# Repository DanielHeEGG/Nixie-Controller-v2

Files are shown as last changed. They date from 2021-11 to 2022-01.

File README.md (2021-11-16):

# Nixie Clock Controller v2
The most overpowered 6-tube nixie clock controller ever created.

For more details on the project, see [Hackaday Page](https://hackaday.io/project/181819-nixie-clock-controller-v2).

Sockets designed to work with this controller are in the [NCv2-Sockets](https://github.com/DanielHeEGG/NCv2-Sockets) repo.

Firmware files are in the [NCv2-Firmware](https://github.com/DanielHeEGG/NCv2-Firmware) repo.

> **WARNING:**
> This project contains EXPOSED and UNMARKED HIGH VOLTAGE contacts, replicate at your own risk.
## License
This project is licensed under the [Creative Commons Attribution-ShareAlike 4.0 International License](http://creativecommons.org/licenses/by-sa/4.0/).

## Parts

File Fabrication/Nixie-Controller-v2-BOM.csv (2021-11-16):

Reference | Quantity | Value | Footprint | Datasheet | Manufacturer | Part#
A1 | 1 | ESP32-WROOM-32E | RF_Module:ESP32-WROOM-32
BT1 | 1 | BACKUP | Battery:BatteryHolder_Keystone_1058_1x2032 | ~ | Keystone | 1058
C1 | 1 | 100uF | Capacitor_Tantalum_SMD:CP_EIA-7343-43_Kemet-X | ~ | Kemet | T510X107M020ATE045
C15 | 1 | 4.7uF | Capacitor_SMD:C_0603_1608Metric | ~ | Yageo | CC0603MRX5R5BB475
C24 | 1 | 47uF | Capacitor_SMD:CP_Elec_5x5.3 | ~ | Nichicon | UWF0J470MCL1GB
C3 | 1 | 10uF | Capacitor_SMD:CP_Elec_10x10 | ~ | Nichicon | UUX2E100MNL1GS
C2 C4 C5 C6 C7 C8 C13 C14 C16 C17 C18 C19 C20 C21 C22 C23 C26 C27 C28 C29 C30 C31 C32 C33 | 24 | 100nF | Capacitor_SMD:C_0402_1005Metric | ~ | Yageo | CC0402KRX7R8BB104
C9 C10 C11 C12 | 4 | 10uF | Capacitor_SMD:CP_Elec_6.3x7.7 | ~ | Nichicon | UUL1H100MCL1GS
D1 | 1 | ~ | Diode_SMD:D_SMB | ~ | Vishay | ES2F
L1 | 1 | 47uH | Inductor_SMD:L_Bourns_SRR1210A | ~ | Bourns | SRR1210A-470M
Q1 | 1 | ~ | Package_TO_SOT_SMD:TO-252-2 | ~ | IXYS | IXFY26N30X3
Q2 Q3 Q4 Q5 Q6 Q7 Q8 Q9 Q10 Q11 Q12 Q13 Q14 Q15 Q16 Q17 Q18 Q19 Q20 Q21 Q22 Q23 Q24 Q25 Q26 Q27 Q28 Q29 Q30 Q31 Q32 Q33 Q34 Q35 Q36 Q37 Q38 Q39 Q40 Q41 Q42 Q43 Q44 Q45 Q46 Q47 Q48 Q49 Q50 Q51 Q52 Q53 Q54 Q55 Q56 Q57 Q58 Q59 Q60 Q61 | 60 | ~ | Package_TO_SOT_SMD:SOT-23 | ~ | Nexperia | MMBTA42
R1 | 1 | 1.2M | Resistor_SMD:R_0805_2012Metric | ~ | Yageo | RC0805FR-071M2L
R14 R29 R40 R51 R62 R73 | 6 | 470 | Resistor_SMD:R_0402_1005Metric | ~ | Yageo | RC0402FR-07470RL
R2 | 1 | 0.05 | Resistor_SMD:R_2010_5025Metric | ~ | Yageo | PE2010FKE070R05L
R3 R4 R5 R6 R7 R8 R9 R10 R11 R12 R13 R15 R16 R17 R18 R19 R20 R21 R22 R23 R24 R25 R26 R27 R30 R31 R32 R33 R34 R35 R36 R37 R38 R39 R41 R42 R43 R44 R45 R46 R47 R48 R49 R50 R52 R53 R54 R55 R56 R57 R58 R59 R60 R61 R63 R64 R65 R66 R67 R68 R69 R70 R71 R72 | 64 | 6.8K | Resistor_SMD:R_0402_1005Metric | ~ | Yageo | RC0402FR-076K8L
RV1 | 1 | 5K | Potentiometer_SMD:Potentiometer_Bourns_3214J_Horizontal | ~ | Bourns | 3214J-1-502E
U1 | 1 | MAX1771 | Package_SO:SOIC-8_3.9x4.9mm_P1.27mm | ~ | Maxim | MAX1771CSA
U11 | 1 | M41T01 | Package_SO:SOIC-8_3.9x4.9mm_P1.27mm | ~ | ST Micro | M41T01M6F
U12 | 1 | STM32F103C8 | Package_QFP:LQFP-48_7x7mm_P0.5mm | ~ | ST Micro | STM32F103C8T6
U9 U13 U15 U17 U19 U21 | 6 | OPA180 | Package_TO_SOT_SMD:SOT-23-5 | ~ | TI | OPA180IDBVT
U10 U14 U16 U18 U20 U22 | 6 | 74HC4067 | Package_SO:SOIC-24W_7.5x15.4mm_P1.27mm | ~ | TI | CD74HC4067M
U2 | 1 | BH2226 | Package_SO:SOIC-16_4.55x10.3mm_P1.27mm | ~ | Rohm Semi | BH2226F-E2
U3 U4 U5 | 3 | 74HC595 | Package_SO:SOIC-16_3.9x9.9mm_P1.27mm | ~ | TI | CD74HC595M
U6 | 1 | SN74LVCC3245A | Package_SO:SO-24_5.3x15mm_P1.27mm | ~ | TI | SN74LVCC3245ANSR
U7 | 1 | NCP1117-5.0 | Package_TO_SOT_SMD:SOT-223-3_TabPin2 | ~ | ON Semi | NCP1117LPST50T3G
U8 | 1 | NCP1117-3.3 | Package_TO_SOT_SMD:SOT-223-3_TabPin2 | ~ | ON Semi | NCP1117LPST33T3G
Y1 | 1 | 32.768KHz | Crystal:Crystal_SMD_2012-2Pin_2.0x1.2mm | ~ | Seiko | SC20S-12.5PF20PPM

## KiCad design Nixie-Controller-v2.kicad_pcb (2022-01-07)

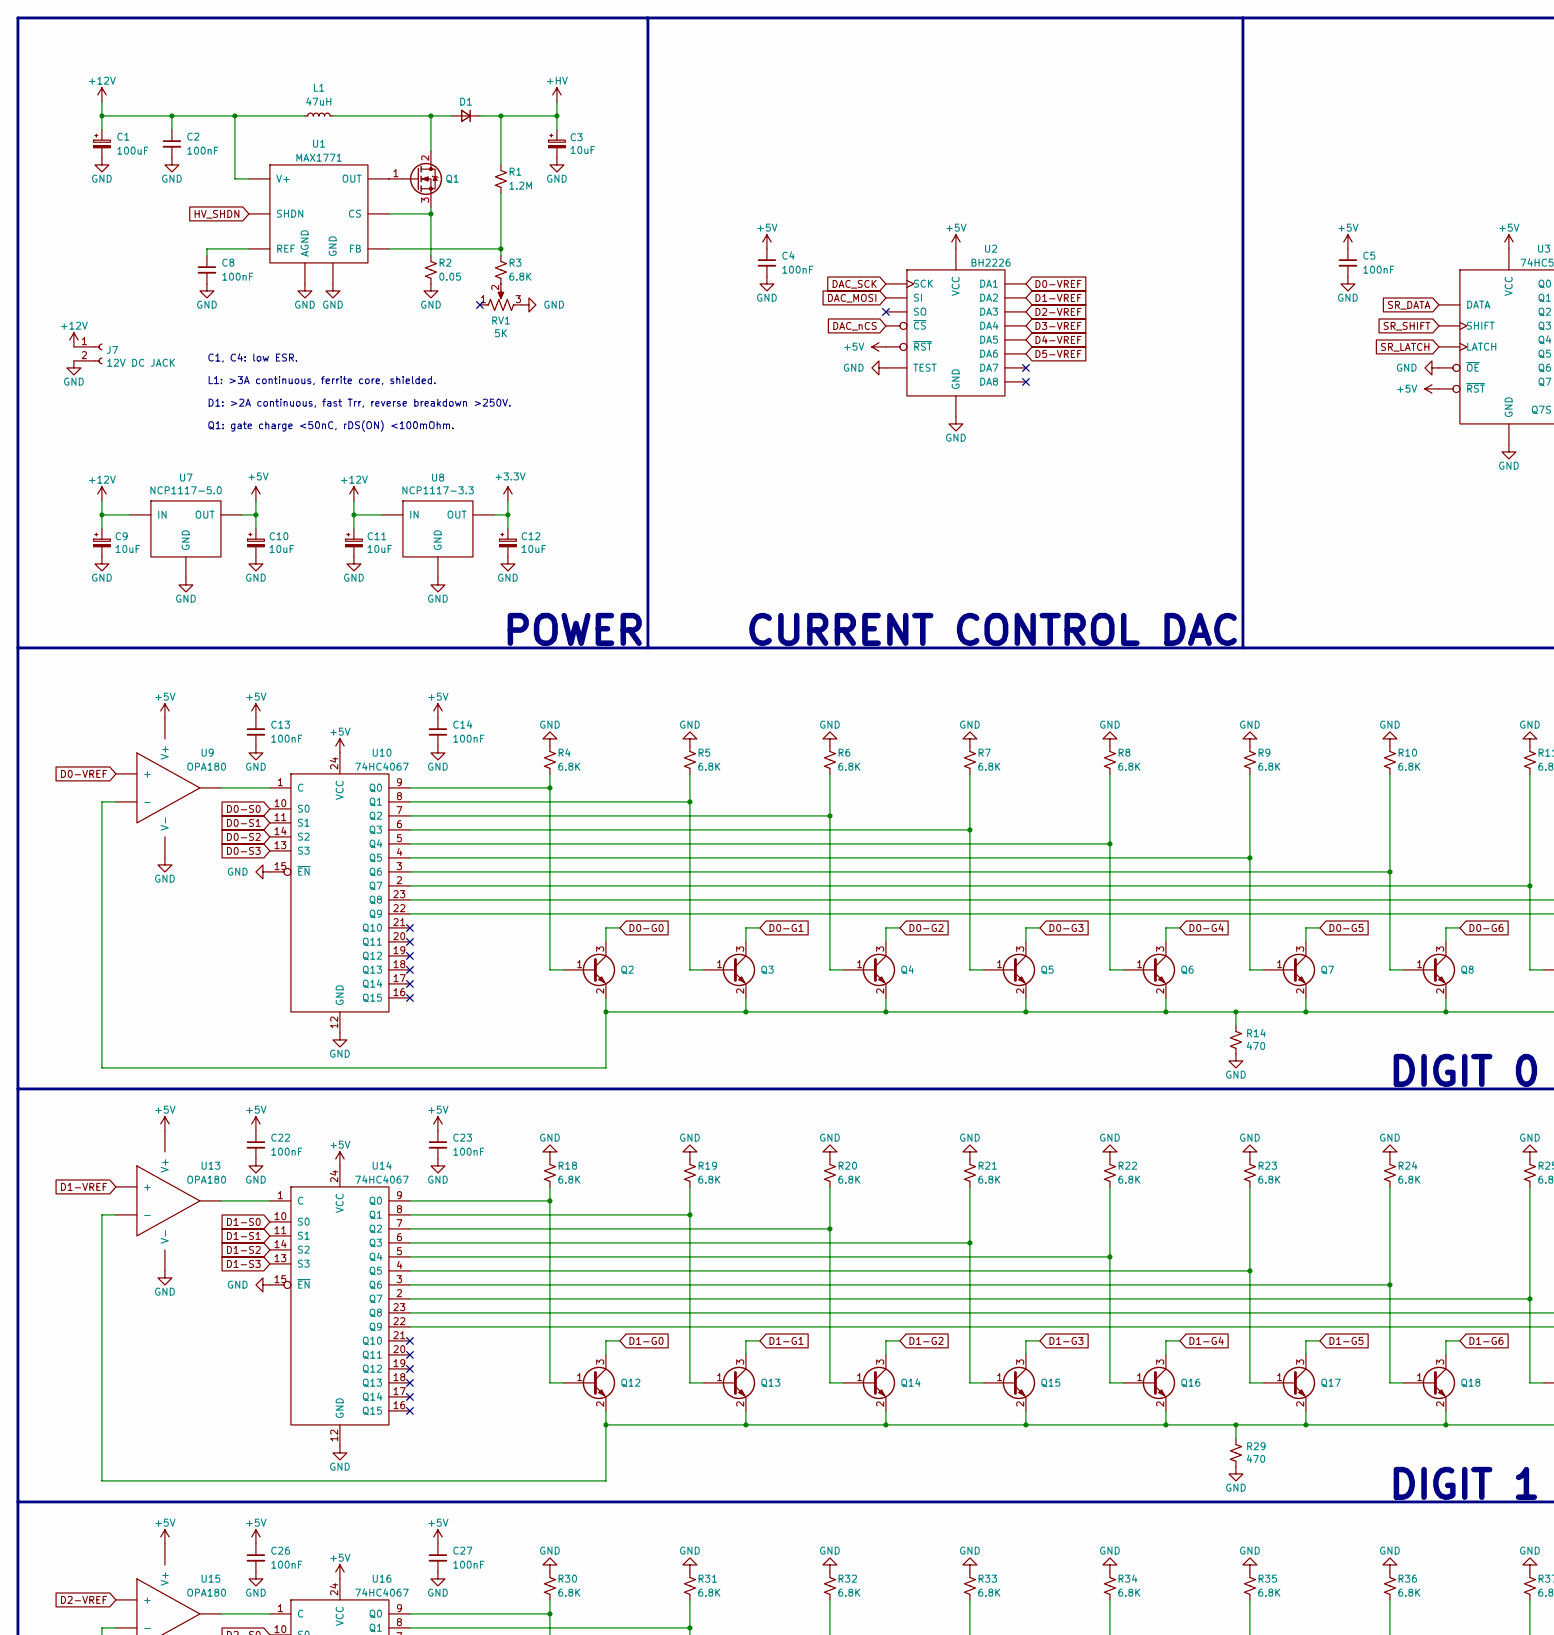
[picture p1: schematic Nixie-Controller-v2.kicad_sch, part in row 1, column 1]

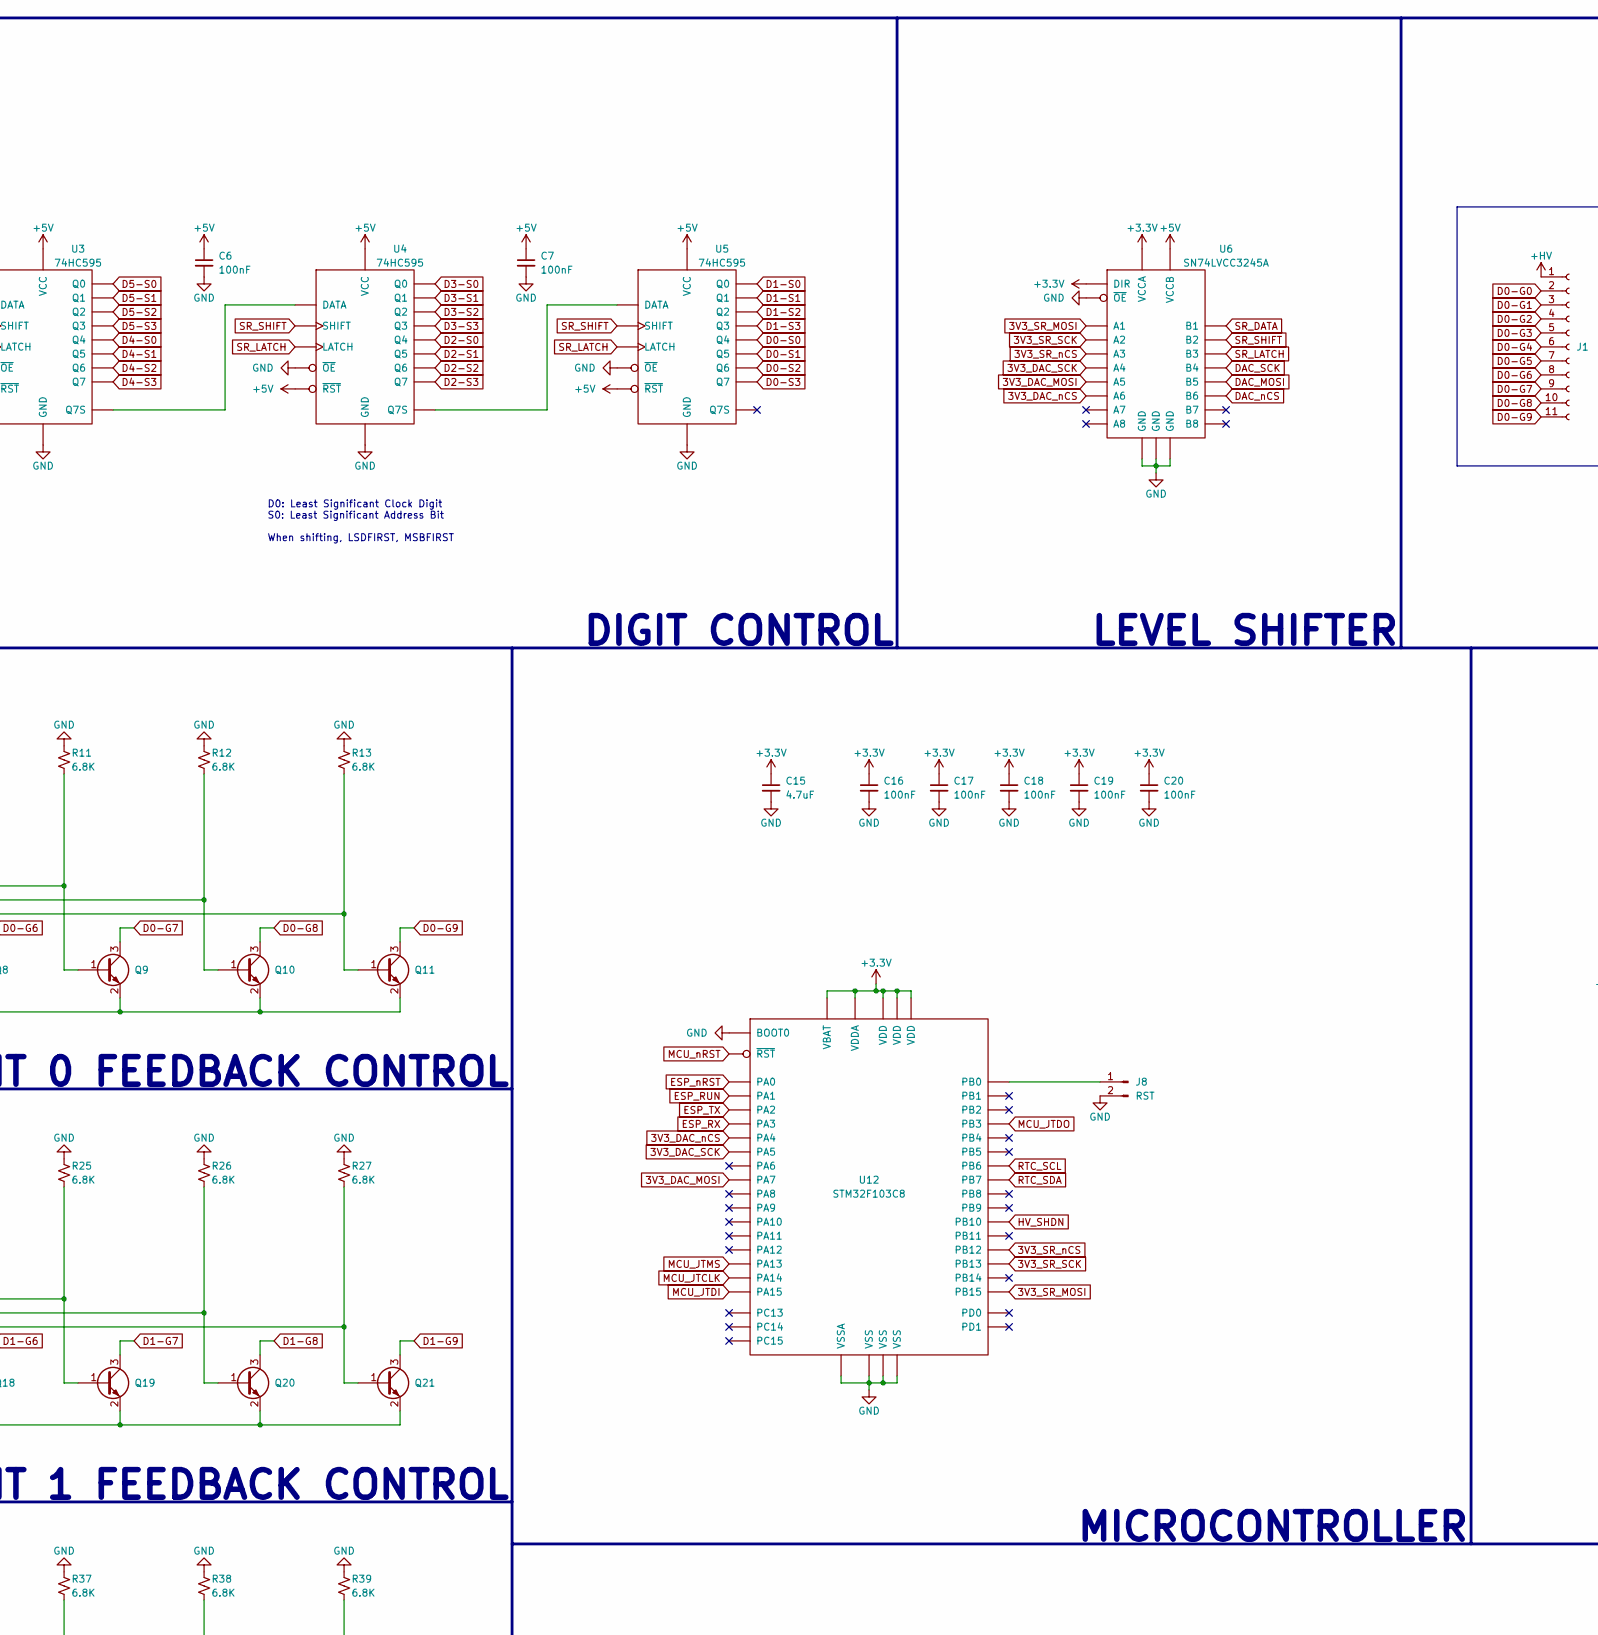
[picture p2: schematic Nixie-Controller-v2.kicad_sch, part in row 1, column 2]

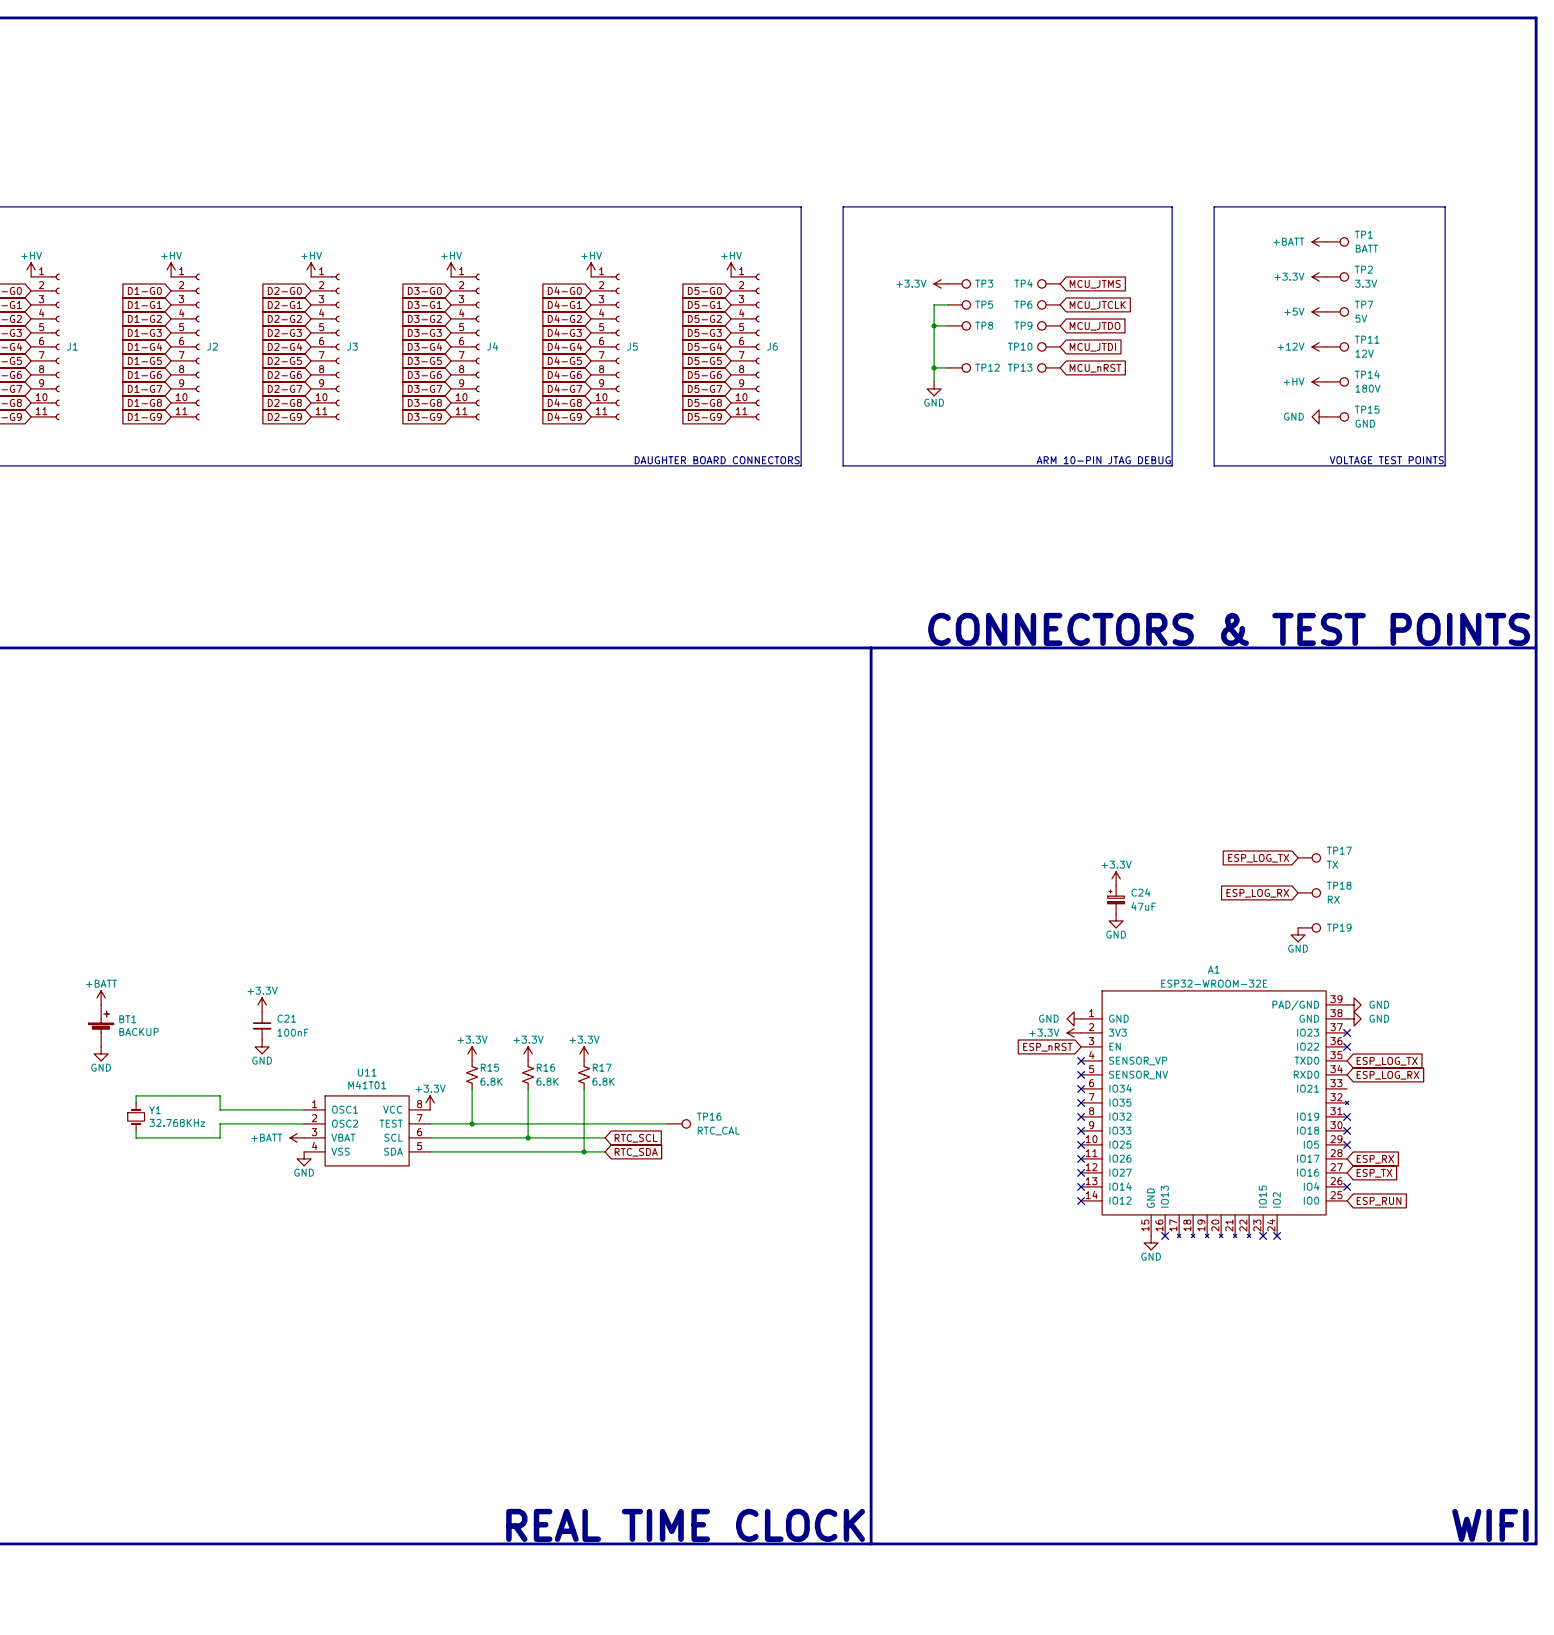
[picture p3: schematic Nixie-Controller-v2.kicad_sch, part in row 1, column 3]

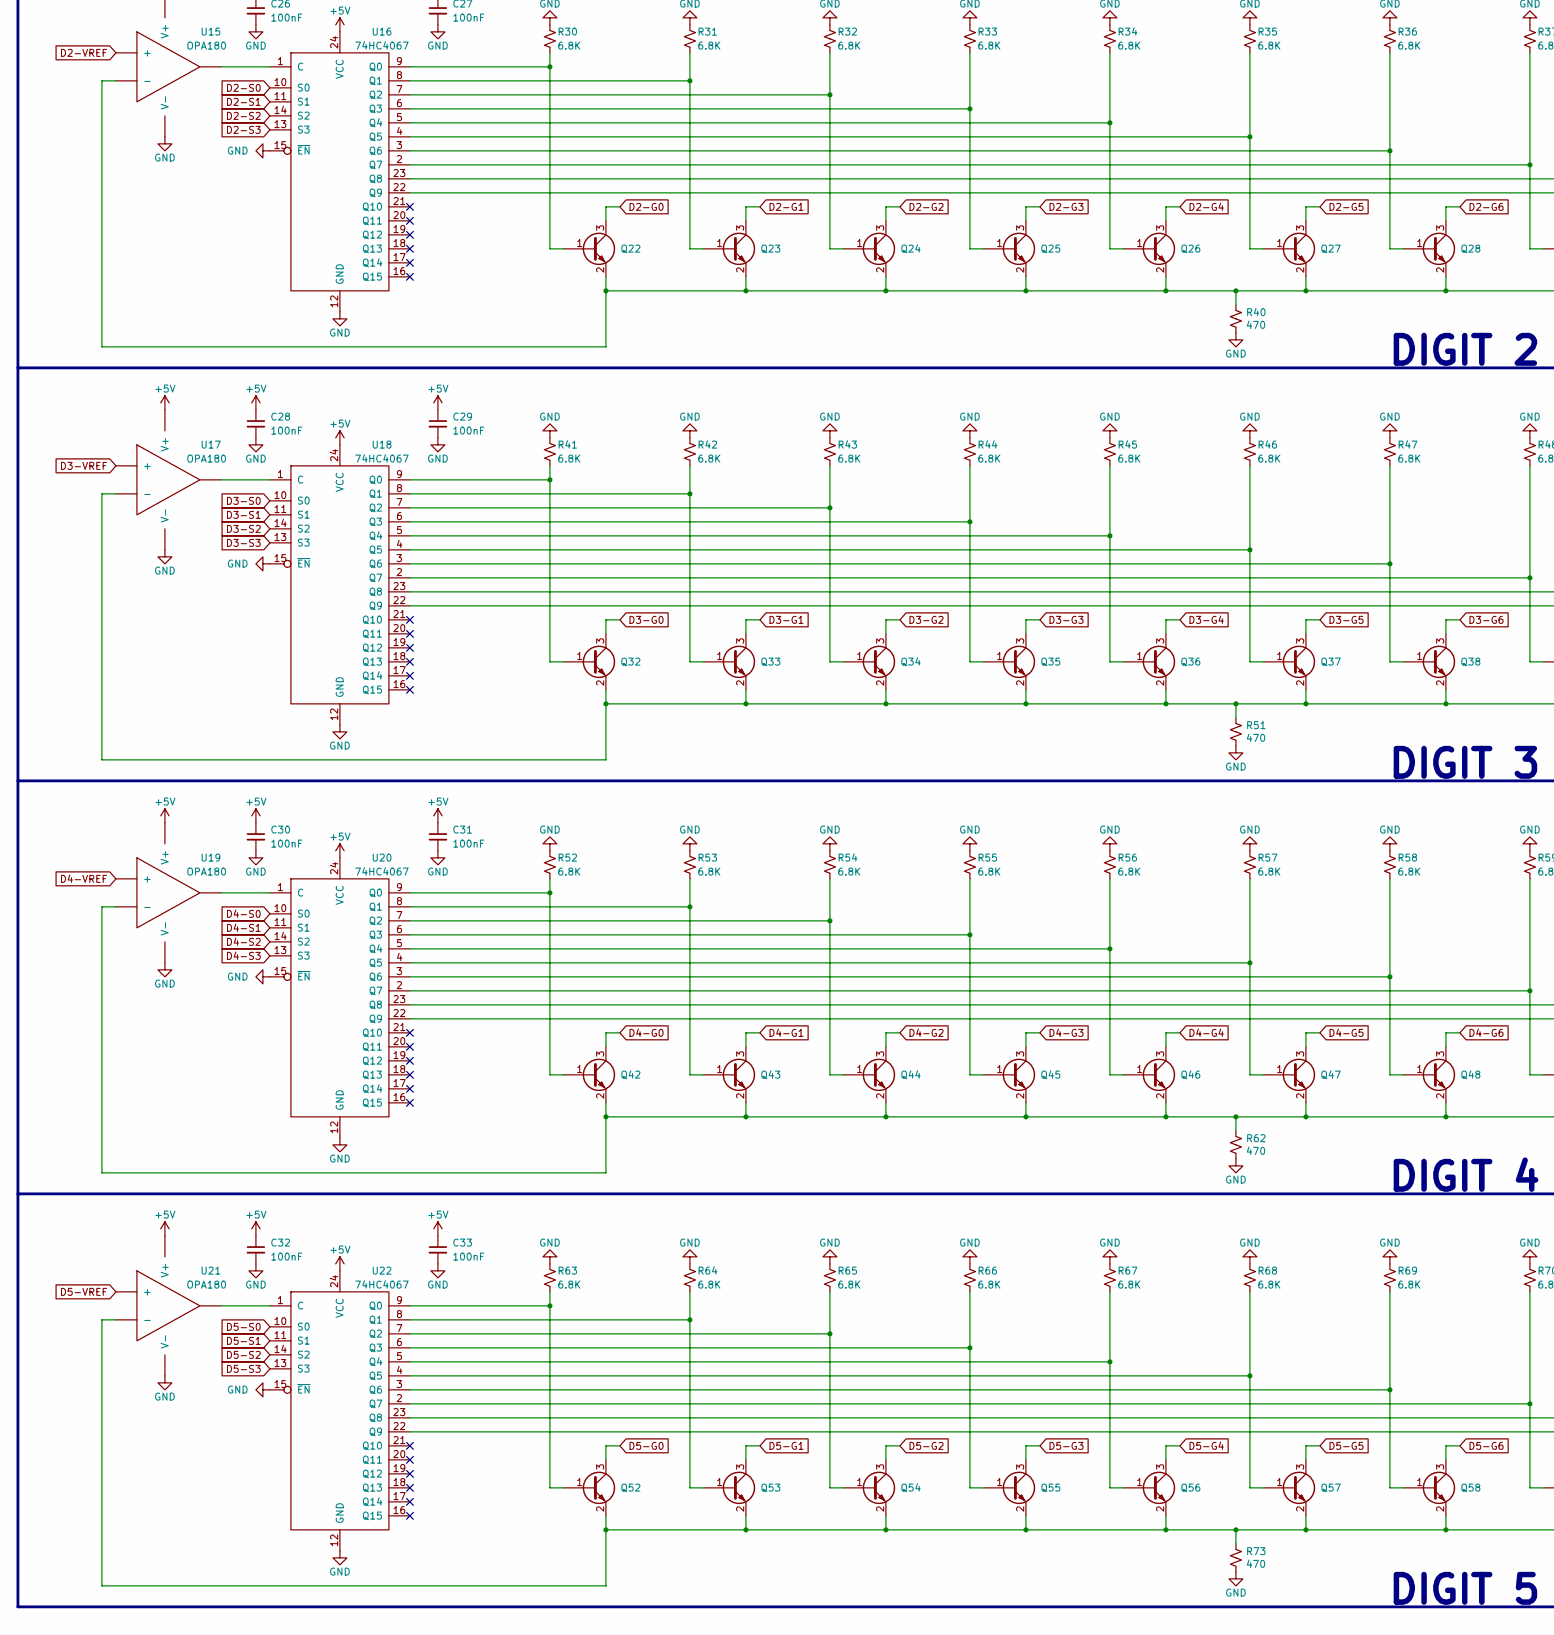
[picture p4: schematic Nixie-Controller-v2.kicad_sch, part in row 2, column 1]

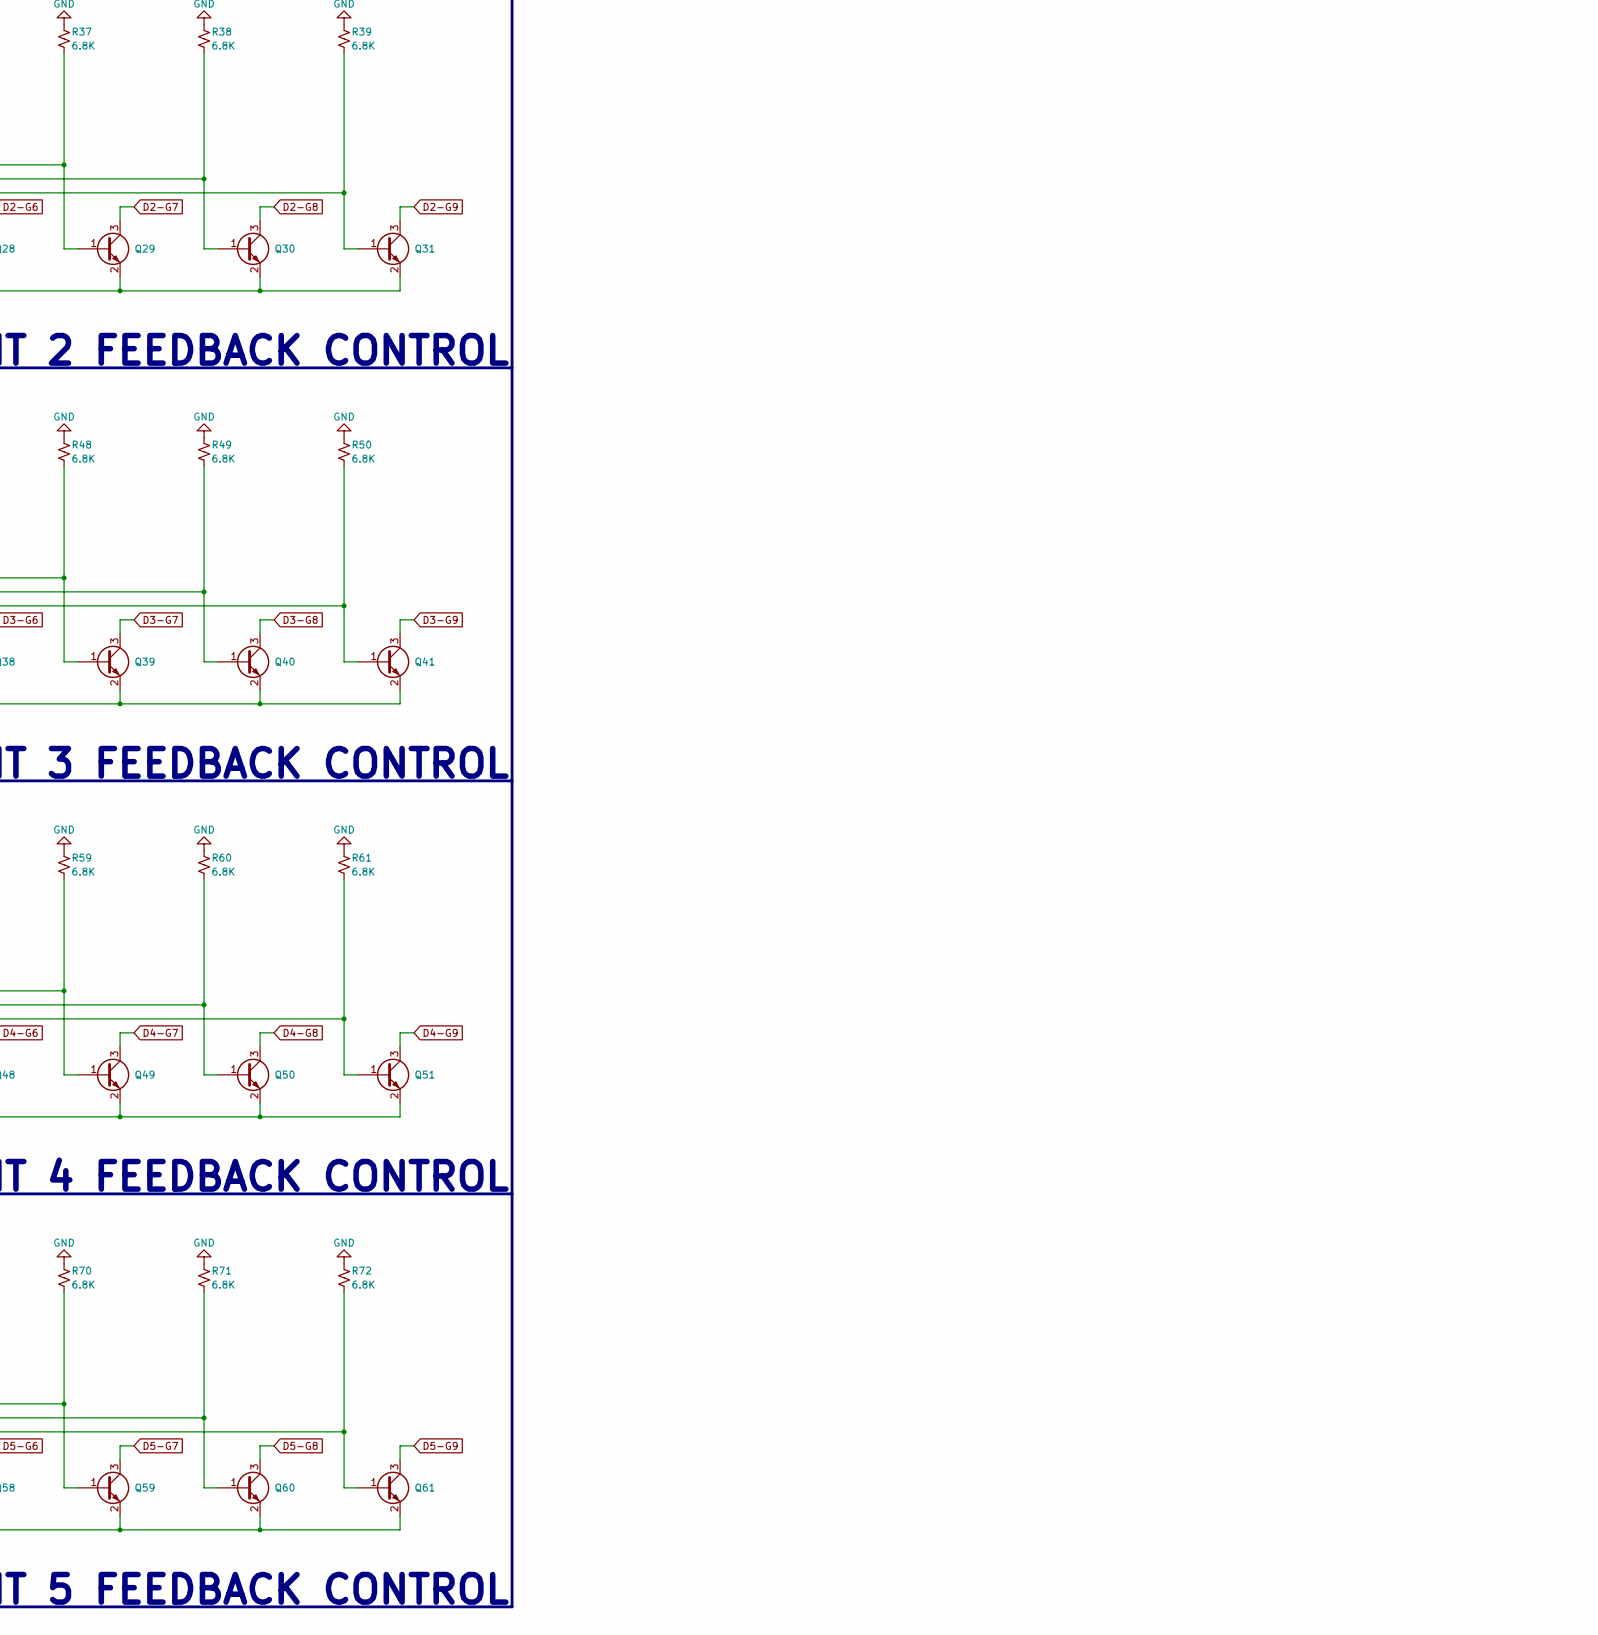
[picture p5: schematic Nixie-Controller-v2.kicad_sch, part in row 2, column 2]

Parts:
A1: ESP32-WROOM-32E; ESP32-WROOM-32
BT1: BACKUP; BatteryHolder_Keystone_1058_1x2032; Part# 1058
C1: 100uF; CP_EIA-7343-43_Kemet-X; Part# T510X107M020ATE045
C2, C4, C5, C6, C7, C8, C13, C14, C16, C17, C18, C19, C20, C21, C22, C23, C26, C27, C28, C29, C30, C31, C32, C33: 100nF; C_0402_1005Metric; Part# CC0402KRX7R8BB104
C3: 10uF; CP_Elec_10x10; Part# UUX2E100MNL1GS
C9, C10, C11, C12: 10uF; CP_Elec_6.3x7.7; Part# UUL1H100MCL1GS
C15: 4.7uF; C_0603_1608Metric; Part# CC0603MRX5R5BB475
C24: 47uF; CP_Elec_5x5.3; Part# UWF0J470MCL1GB
D1: D_SMB; Part# ES2F
J1, J2, J3, J4, J5, J6: PinSocket_1x11_P2.54mm_Vertical
J7: 12V DC JACK; BarrelJack_Horizontal
J8: RST; PinHeader_1x02_P2.54mm_Vertical
L1: 47uH; L_Bourns_SRR1210A; Part# SRR1210A-470M
Q1: TO-252-2; Part# IXFY26N30X3
Q2, Q3, Q4, Q5, Q6, Q7, Q8, Q9, Q10, Q11, Q12, Q13, Q14, Q15, Q16, Q17, Q18, Q19, Q20, Q21, Q22, Q23, Q24, Q25, Q26, Q27, Q28, Q29, Q30, Q31, Q32, Q33, Q34, Q35, Q36, Q37, Q38, Q39, Q40, Q41, Q42, Q43, Q44, Q45, Q46, Q47, Q48, Q49, Q50, Q51, Q52, Q53, Q54, Q55, Q56, Q57, Q58, Q59, Q60, Q61: SOT-23; Part# MMBTA42
R1: 1.2M; R_0805_2012Metric; Part# RC0805FR-071M2L
R2: 0.05; R_2010_5025Metric; Part# PE2010FKE070R05L
R3, R4, R5, R6, R7, R8, R9, R10, R11, R12, R13, R15, R16, R17, R18, R19, R20, R21, R22, R23, R24, R25, R26, R27, R30, R31, R32, R33, R34, R35, R36, R37, R38, R39, R41, R42, R43, R44, R45, R46, R47, R48, R49, R50, R52, R53, R54, R55, R56, R57, R58, R59, R60, R61, R63, R64, R65, R66, R67, R68, R69, R70, R71, R72: 6.8K; R_0402_1005Metric; Part# RC0402FR-076K8L
R14, R29, R40, R51, R62, R73: 470; R_0402_1005Metric; Part# RC0402FR-07470RL
RV1: 5K; Potentiometer_Bourns_3214J_Horizontal; Part# 3214J-1-502E
TP1: BATT; TestPoint_Pad_D1.5mm
TP2: 3.3V; TestPoint_Pad_D1.5mm
TP3, TP4, TP5, TP6, TP8, TP9, TP10, TP12, TP13, TP19: TestPoint_Pad_D1.5mm
TP7: 5V; TestPoint_Pad_D1.5mm
TP11: 12V; TestPoint_Pad_D1.5mm
TP14: 180V; TestPoint_Pad_D1.5mm
TP15: GND; TestPoint_Pad_D1.5mm
TP16: RTC_CAL; TestPoint_Pad_D1.5mm
TP17: TX; TestPoint_Pad_D1.5mm
TP18: RX; TestPoint_Pad_D1.5mm
U1: MAX1771; SOIC-8_3.9x4.9mm_P1.27mm; Part# MAX1771CSA
U2: BH2226; SOIC-16_4.55x10.3mm_P1.27mm; Part# BH2226F-E2
U3, U4, U5: 74HC595; SOIC-16_3.9x9.9mm_P1.27mm; Part# CD74HC595M
U6: SN74LVCC3245A; SO-24_5.3x15mm_P1.27mm; Part# SN74LVCC3245ANSR
U7: NCP1117-5.0; SOT-223-3_TabPin2; Part# NCP1117LPST50T3G
U8: NCP1117-3.3; SOT-223-3_TabPin2; Part# NCP1117LPST33T3G
U9, U13, U15, U17, U19, U21: OPA180; SOT-23-5; Part# OPA180IDBVT
U10, U14, U16, U18, U20, U22: 74HC4067; SOIC-24W_7.5x15.4mm_P1.27mm; Part# CD74HC4067M
U11: M41T01; SOIC-8_3.9x4.9mm_P1.27mm; Part# M41T01M6F
U12: STM32F103C8; LQFP-48_7x7mm_P0.5mm; Part# STM32F103C8T6
Y1: 32.768KHz; Crystal_SMD_2012-2Pin_2.0x1.2mm; Part# SC20S-12.5PF20PPM

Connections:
3V3_DAC_MOSI: U6.7 (A5), U12.17 (PA7)
3V3_DAC_SCK: U6.6 (A4), U12.15 (PA5)
3V3_DAC_nCS: U6.8 (A6), U12.14 (PA4)
3V3_SR_MOSI: U6.3 (A1), U12.28 (PB15)
3V3_SR_SCK: U6.4 (A2), U12.26 (PB13)
3V3_SR_nCS: U6.5 (A3), U12.25 (PB12)
+3V3: A1.2 (3V3), C12.1, C15.1, C16.1, C17.1, C18.1, C19.1, C20.1, C21.1, C24.1, R15.1, R16.1, R17.1, TP2.1, TP3.1, U6.1 (VCCA), U6.2 (DIR), U8.2 (OUT), U11.8 (VCC), U12.1 (VBAT), U12.9 (VDDA), U12.24 (VDD), U12.36 (VDD), U12.48 (VDD)
+5V: C4.1, C5.1, C6.1, C7.1, C10.1, C13.1, C14.1, C22.1, C23.1, C26.1, C27.1, C28.1, C29.1, C30.1, C31.1, C32.1, C33.1, TP7.1, U2.9 (VCC), U2.10 (~RST), U3.10 (~RST), U3.16 (VCC), U4.10 (~RST), U4.16 (VCC), U5.10 (~RST), U5.16 (VCC), U6.24 (VCCB), U7.2 (OUT), U9.5 (V+), U10.24 (VCC), U13.5 (V+), U14.24 (VCC), U15.5 (V+), U16.24 (VCC), U17.5 (V+), U18.24 (VCC), U19.5 (V+), U20.24 (VCC), U21.5 (V+), U22.24 (VCC)
+12V: C1.1, C2.1, C9.1, C11.1, J7.1, L1.1, TP11.1, U1.2 (V+), U7.3 (IN), U8.3 (IN)
+BATT: BT1.1 (+), TP1.1, U11.3 (VBAT)
+HV: C3.1, D1.1 (K), J1.1, J2.1, J3.1, J4.1, J5.1, J6.1, R1.1, TP14.1
D0-G0: J1.2, Q2.3 (C)
D0-G1: J1.3, Q3.3 (C)
D0-G2: J1.4, Q4.3 (C)
D0-G3: J1.5, Q5.3 (C)
D0-G4: J1.6, Q6.3 (C)
D0-G5: J1.7, Q7.3 (C)
D0-G6: J1.8, Q8.3 (C)
D0-G7: J1.9, Q9.3 (C)
D0-G8: J1.10, Q10.3 (C)
D0-G9: J1.11, Q11.3 (C)
D0-S0: U5.4 (Q4), U10.10 (S0)
D0-S1: U5.5 (Q5), U10.11 (S1)
D0-S2: U5.6 (Q6), U10.14 (S2)
D0-S3: U5.7 (Q7), U10.13 (S3)
D0-VREF: U2.1 (DA1), U9.3 (+)
D1-G0: J2.2, Q12.3 (C)
D1-G1: J2.3, Q13.3 (C)
D1-G2: J2.4, Q14.3 (C)
D1-G3: J2.5, Q15.3 (C)
D1-G4: J2.6, Q16.3 (C)
D1-G5: J2.7, Q17.3 (C)
D1-G6: J2.8, Q18.3 (C)
D1-G7: J2.9, Q19.3 (C)
D1-G8: J2.10, Q20.3 (C)
D1-G9: J2.11, Q21.3 (C)
D1-S0: U5.15 (Q0), U14.10 (S0)
D1-S1: U5.1 (Q1), U14.11 (S1)
D1-S2: U5.2 (Q2), U14.14 (S2)
D1-S3: U5.3 (Q3), U14.13 (S3)
D1-VREF: U2.2 (DA2), U13.3 (+)
D2-G0: J3.2, Q22.3 (C)
D2-G1: J3.3, Q23.3 (C)
D2-G2: J3.4, Q24.3 (C)
D2-G3: J3.5, Q25.3 (C)
D2-G4: J3.6, Q26.3 (C)
D2-G5: J3.7, Q27.3 (C)
D2-G6: J3.8, Q28.3 (C)
D2-G7: J3.9, Q29.3 (C)
D2-G8: J3.10, Q30.3 (C)
D2-G9: J3.11, Q31.3 (C)
D2-S0: U4.4 (Q4), U16.10 (S0)
D2-S1: U4.5 (Q5), U16.11 (S1)
D2-S2: U4.6 (Q6), U16.14 (S2)
D2-S3: U4.7 (Q7), U16.13 (S3)
D2-VREF: U2.3 (DA3), U15.3 (+)
D3-G0: J4.2, Q32.3 (C)
D3-G1: J4.3, Q33.3 (C)
D3-G2: J4.4, Q34.3 (C)
D3-G3: J4.5, Q35.3 (C)
D3-G4: J4.6, Q36.3 (C)
D3-G5: J4.7, Q37.3 (C)
D3-G6: J4.8, Q38.3 (C)
D3-G7: J4.9, Q39.3 (C)
D3-G8: J4.10, Q40.3 (C)
D3-G9: J4.11, Q41.3 (C)
D3-S0: U4.15 (Q0), U18.10 (S0)
D3-S1: U4.1 (Q1), U18.11 (S1)
D3-S2: U4.2 (Q2), U18.14 (S2)
D3-S3: U4.3 (Q3), U18.13 (S3)
D3-VREF: U2.4 (DA4), U17.3 (+)
D4-G0: J5.2, Q42.3 (C)
D4-G1: J5.3, Q43.3 (C)
D4-G2: J5.4, Q44.3 (C)
D4-G3: J5.5, Q45.3 (C)
D4-G4: J5.6, Q46.3 (C)
D4-G5: J5.7, Q47.3 (C)
D4-G6: J5.8, Q48.3 (C)
D4-G7: J5.9, Q49.3 (C)
D4-G8: J5.10, Q50.3 (C)
D4-G9: J5.11, Q51.3 (C)
D4-S0: U3.4 (Q4), U20.10 (S0)
D4-S1: U3.5 (Q5), U20.11 (S1)
D4-S2: U3.6 (Q6), U20.14 (S2)
D4-S3: U3.7 (Q7), U20.13 (S3)
D4-VREF: U2.5 (DA5), U19.3 (+)
D5-G0: J6.2, Q52.3 (C)
D5-G1: J6.3, Q53.3 (C)
D5-G2: J6.4, Q54.3 (C)
D5-G3: J6.5, Q55.3 (C)
D5-G4: J6.6, Q56.3 (C)
D5-G5: J6.7, Q57.3 (C)
D5-G6: J6.8, Q58.3 (C)
D5-G7: J6.9, Q59.3 (C)
D5-G8: J6.10, Q60.3 (C)
D5-G9: J6.11, Q61.3 (C)
D5-S0: U3.15 (Q0), U22.10 (S0)
D5-S1: U3.1 (Q1), U22.11 (S1)
D5-S2: U3.2 (Q2), U22.14 (S2)
D5-S3: U3.3 (Q3), U22.13 (S3)
D5-VREF: U2.6 (DA6), U21.3 (+)
DAC_MOSI: U2.14 (SI), U6.17 (B5)
DAC_SCK: U2.13 (SCK), U6.18 (B4)
DAC_nCS: U2.12 (~CS), U6.16 (B6)
ESP_LOG_RX: A1.34 (RXD0), TP18.1
ESP_LOG_TX: A1.35 (TXD0), TP17.1
ESP_RUN: A1.25 (IO0), U12.11 (PA1)
ESP_RX: A1.28 (IO17), U12.13 (PA3)
ESP_TX: A1.27 (IO16), U12.12 (PA2)
ESP_nRST: A1.3 (EN), U12.10 (PA0)
GND: A1.1 (GND), A1.15 (GND), A1.38 (GND), A1.39 (PAD/GND), BT1.2 (-), C1.2, C2.2, C3.2, C4.2, C5.2, C6.2, C7.2, C8.2, C9.2, C10.2, C11.2, C12.2, C13.2, C14.2, C15.2, C16.2, C17.2, C18.2, C19.2, C20.2, C21.2, C22.2, C23.2, C24.2, C26.2, C27.2, C28.2, C29.2, C30.2, C31.2, C32.2, C33.2, J7.2, J8.2, R2.2, R4.1, R5.1, R6.1, R7.1, R8.1, R9.1, R10.1, R11.1, R12.1, R13.1, R14.2, R18.1, R19.1, R20.1, R21.1, R22.1, R23.1, R24.1, R25.1, R26.1, R27.1, R29.2, R30.1, R31.1, R32.1, R33.1, R34.1, R35.1, R36.1, R37.1, R38.1, R39.1, R40.2, R41.1, R42.1, R43.1, R44.1, R45.1, R46.1, R47.1, R48.1, R49.1, R50.1, R51.2, R52.1, R53.1, R54.1, R55.1, R56.1, R57.1, R58.1, R59.1, R60.1, R61.1, R62.2, R63.1, R64.1, R65.1, R66.1, R67.1, R68.1, R69.1, R70.1, R71.1, R72.1, R73.2, RV1.3, TP5.1, TP8.1, TP12.1, TP15.1, TP19.1, U1.6 (AGND), U1.7 (GND), U2.11 (TEST), U2.16 (GND), U3.8 (GND), U3.13 (~OE), U4.8 (GND), U4.13 (~OE), U5.8 (GND), U5.13 (~OE), U6.11 (GND), U6.12 (GND), U6.13 (GND), U6.22 (~OE), U7.1 (GND), U8.1 (GND), U9.2 (V-), U10.12 (GND), U10.15 (~EN), U11.4 (VSS), U12.8 (VSSA), U12.23 (VSS), U12.35 (VSS), U12.44 (BOOT0), U12.47 (VSS), U13.2 (V-), U14.12 (GND), U14.15 (~EN), U15.2 (V-), U16.12 (GND), U16.15 (~EN), U17.2 (V-), U18.12 (GND), U18.15 (~EN), U19.2 (V-), U20.12 (GND), U20.15 (~EN), U21.2 (V-), U22.12 (GND), U22.15 (~EN)
HV_SHDN: U1.4 (SHDN), U12.21 (PB10)
MCU_JTCLK: TP6.1, U12.37 (PA14)
MCU_JTDI: TP10.1, U12.38 (PA15)
MCU_JTDO: TP9.1, U12.39 (PB3)
MCU_JTMS: TP4.1, U12.34 (PA13)
MCU_nRST: TP13.1, U12.7 (~RST)
unnamed: C8.1, U1.5 (REF)
unnamed: D1.2 (A), L1.2, Q1.2 (D)
unnamed: J8.1, U12.18 (PB0)
unnamed: Q1.1 (G), U1.1 (OUT)
unnamed: Q1.3 (S), R2.1, U1.8 (CS)
unnamed: Q2.1 (B), R4.2, U10.9 (Q0)
unnamed: Q3.1 (B), R5.2, U10.8 (Q1)
unnamed: Q4.1 (B), R6.2, U10.7 (Q2)
unnamed: Q5.1 (B), R7.2, U10.6 (Q3)
unnamed: Q6.1 (B), R8.2, U10.5 (Q4)
unnamed: Q7.1 (B), R9.2, U10.4 (Q5)
unnamed: Q8.1 (B), R10.2, U10.3 (Q6)
unnamed: Q9.1 (B), R11.2, U10.2 (Q7)
unnamed: Q10.1 (B), R12.2, U10.23 (Q8)
unnamed: Q2.2 (E), Q3.2 (E), Q4.2 (E), Q5.2 (E), Q6.2 (E), Q7.2 (E), Q8.2 (E), Q9.2 (E), Q10.2 (E), Q11.2 (E), R14.1, U9.4 (-)
unnamed: Q11.1 (B), R13.2, U10.22 (Q9)
unnamed: Q12.1 (B), R18.2, U14.9 (Q0)
unnamed: Q12.2 (E), Q13.2 (E), Q14.2 (E), Q15.2 (E), Q16.2 (E), Q17.2 (E), Q18.2 (E), Q19.2 (E), Q20.2 (E), Q21.2 (E), R29.1, U13.4 (-)
unnamed: Q13.1 (B), R19.2, U14.8 (Q1)
unnamed: Q14.1 (B), R20.2, U14.7 (Q2)
unnamed: Q15.1 (B), R21.2, U14.6 (Q3)
unnamed: Q16.1 (B), R22.2, U14.5 (Q4)
unnamed: Q17.1 (B), R23.2, U14.4 (Q5)
unnamed: Q18.1 (B), R24.2, U14.3 (Q6)
unnamed: Q19.1 (B), R25.2, U14.2 (Q7)
unnamed: Q20.1 (B), R26.2, U14.23 (Q8)
unnamed: Q21.1 (B), R27.2, U14.22 (Q9)
unnamed: Q22.1 (B), R30.2, U16.9 (Q0)
unnamed: Q22.2 (E), Q23.2 (E), Q24.2 (E), Q25.2 (E), Q26.2 (E), Q27.2 (E), Q28.2 (E), Q29.2 (E), Q30.2 (E), Q31.2 (E), R40.1, U15.4 (-)
unnamed: Q23.1 (B), R31.2, U16.8 (Q1)
unnamed: Q24.1 (B), R32.2, U16.7 (Q2)
unnamed: Q25.1 (B), R33.2, U16.6 (Q3)
unnamed: Q26.1 (B), R34.2, U16.5 (Q4)
unnamed: Q27.1 (B), R35.2, U16.4 (Q5)
unnamed: Q28.1 (B), R36.2, U16.3 (Q6)
unnamed: Q29.1 (B), R37.2, U16.2 (Q7)
unnamed: Q30.1 (B), R38.2, U16.23 (Q8)
unnamed: Q31.1 (B), R39.2, U16.22 (Q9)
unnamed: Q32.1 (B), R41.2, U18.9 (Q0)
unnamed: Q32.2 (E), Q33.2 (E), Q34.2 (E), Q35.2 (E), Q36.2 (E), Q37.2 (E), Q38.2 (E), Q39.2 (E), Q40.2 (E), Q41.2 (E), R51.1, U17.4 (-)
unnamed: Q33.1 (B), R42.2, U18.8 (Q1)
unnamed: Q34.1 (B), R43.2, U18.7 (Q2)
unnamed: Q35.1 (B), R44.2, U18.6 (Q3)
unnamed: Q36.1 (B), R45.2, U18.5 (Q4)
unnamed: Q37.1 (B), R46.2, U18.4 (Q5)
unnamed: Q38.1 (B), R47.2, U18.3 (Q6)
unnamed: Q39.1 (B), R48.2, U18.2 (Q7)
unnamed: Q40.1 (B), R49.2, U18.23 (Q8)
unnamed: Q41.1 (B), R50.2, U18.22 (Q9)
unnamed: Q42.1 (B), R52.2, U20.9 (Q0)
unnamed: Q42.2 (E), Q43.2 (E), Q44.2 (E), Q45.2 (E), Q46.2 (E), Q47.2 (E), Q48.2 (E), Q49.2 (E), Q50.2 (E), Q51.2 (E), R62.1, U19.4 (-)
unnamed: Q43.1 (B), R53.2, U20.8 (Q1)
unnamed: Q44.1 (B), R54.2, U20.7 (Q2)
unnamed: Q45.1 (B), R55.2, U20.6 (Q3)
unnamed: Q46.1 (B), R56.2, U20.5 (Q4)
unnamed: Q47.1 (B), R57.2, U20.4 (Q5)
unnamed: Q48.1 (B), R58.2, U20.3 (Q6)
unnamed: Q49.1 (B), R59.2, U20.2 (Q7)
unnamed: Q50.1 (B), R60.2, U20.23 (Q8)
unnamed: Q51.1 (B), R61.2, U20.22 (Q9)
unnamed: Q52.1 (B), R63.2, U22.9 (Q0)
unnamed: Q52.2 (E), Q53.2 (E), Q54.2 (E), Q55.2 (E), Q56.2 (E), Q57.2 (E), Q58.2 (E), Q59.2 (E), Q60.2 (E), Q61.2 (E), R73.1, U21.4 (-)
unnamed: Q53.1 (B), R64.2, U22.8 (Q1)
unnamed: Q54.1 (B), R65.2, U22.7 (Q2)
unnamed: Q55.1 (B), R66.2, U22.6 (Q3)
unnamed: Q56.1 (B), R67.2, U22.5 (Q4)
unnamed: Q57.1 (B), R68.2, U22.4 (Q5)
unnamed: Q58.1 (B), R69.2, U22.3 (Q6)
unnamed: Q59.1 (B), R70.2, U22.2 (Q7)
unnamed: Q60.1 (B), R71.2, U22.23 (Q8)
unnamed: Q61.1 (B), R72.2, U22.22 (Q9)
unnamed: R1.2, R3.1, U1.3 (FB)
unnamed: R3.2, RV1.2
unnamed: R15.2, TP16.1, U11.7 (TEST)
unnamed: U3.9 (Q7S), U4.14 (DATA)
unnamed: U4.9 (Q7S), U5.14 (DATA)
unnamed: U9.1, U10.1 (C)
unnamed: U11.1 (OSC1), Y1.1
unnamed: U11.2 (OSC2), Y1.2
unnamed: U13.1, U14.1 (C)
unnamed: U15.1, U16.1 (C)
unnamed: U17.1, U18.1 (C)
unnamed: U19.1, U20.1 (C)
unnamed: U21.1, U22.1 (C)
RTC_SCL: R16.2, U11.6 (SCL), U12.42 (PB6)
RTC_SDA: R17.2, U11.5 (SDA), U12.43 (PB7)
SR_DATA: U3.14 (DATA), U6.21 (B1)
SR_LATCH: U3.12 (LATCH), U4.12 (LATCH), U5.12 (LATCH), U6.19 (B3)
SR_SHIFT: U3.11 (SHIFT), U4.11 (SHIFT), U5.11 (SHIFT), U6.20 (B2)

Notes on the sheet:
CONNECTORS & TEST POINTS
DIGIT 0 FEEDBACK CONTROL
DAUGHTER BOARD CONNECTORS
VOLTAGE TEST POINTS
D0: Least Significant Clock Digit S0: Least Significant Address Bit When shifting, LSDFIRST, MSBFIRST
DIGIT 4 FEEDBACK CONTROL
CURRENT CONTROL DAC
WIFI
DIGIT 5 FEEDBACK CONTROL
DIGIT 2 FEEDBACK CONTROL
MICROCONTROLLER
REAL TIME CLOCK
DIGIT 3 FEEDBACK CONTROL
ARM 10-PIN JTAG DEBUG
LEVEL SHIFTER
POWER
C1, C4: low ESR. L1: >3A continuous, ferrite core, shielded. D1: >2A continuous, fast Trr, reverse breakdown >250V. Q1: gate charge <50nC, rDS(ON) <100mOhm.
DIGIT CONTROL
DIGIT 1 FEEDBACK CONTROL

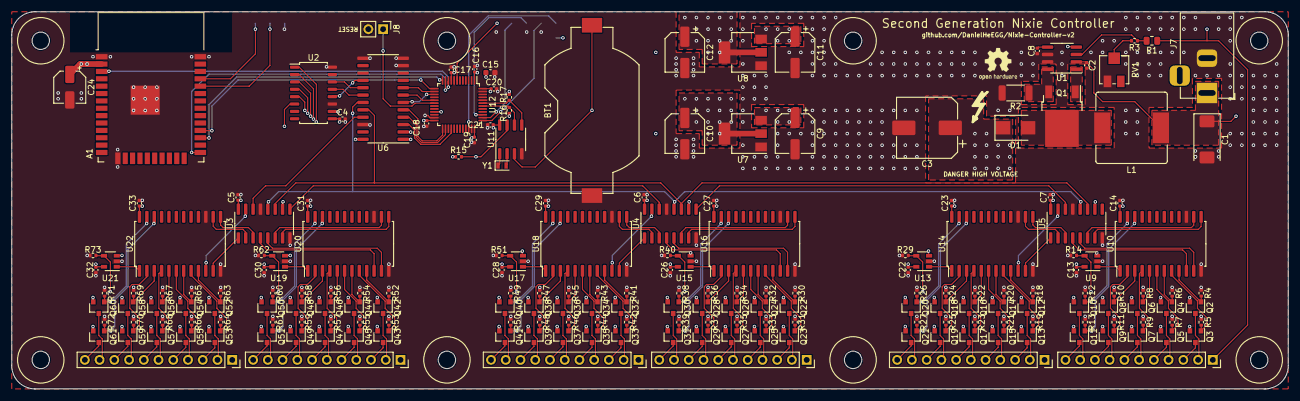
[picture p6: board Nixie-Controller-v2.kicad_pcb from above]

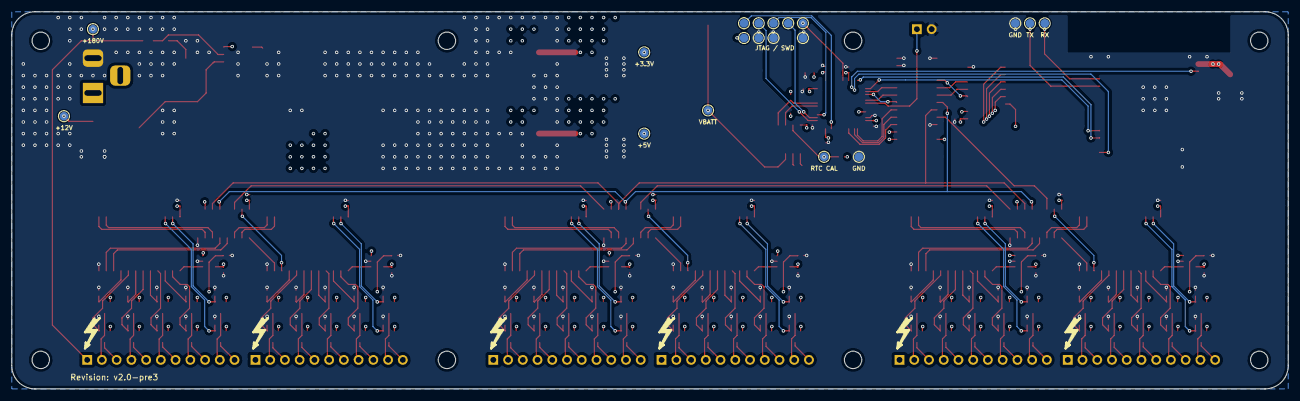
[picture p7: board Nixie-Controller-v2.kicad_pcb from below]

Board: 4 copper layers, 220.0 x 65.0 mm, 220 parts (19 on the bottom side), 206 nets.

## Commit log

2021-09-02 Add power supply
    [Nixie-Controller-v2.kicad_pcb, Nixie-Controller-v2.sch]
2021-10-05 Optimize power supply inductor
    [Nixie-Controller-v2.sch]
2021-10-06 Add tube driving circuitry
    [Nixie-Controller-v2.sch]
2021-10-07 Add uC and component selection
    [Nixie-Controller-v2.sch]
2021-10-07 Add voltage test points
    [Nixie-Controller-v2.sch]
2021-10-07 Assign footprint to test points
    [Nixie-Controller-v2.sch]
2021-10-07 Add RTC
    [Nixie-Controller-v2.sch]
2021-10-07 Fix DRC issues
    [Nixie-Controller-v2.sch]
2021-10-07 Add RTC I2C port to uC config
2021-10-07 Add DC barrel jack
    [Nixie-Controller-v2.sch]
2021-10-07 Add PCB layout
    [Nixie-Controller-v2.kicad_pcb]
2021-10-07 Generate fabrication files
    [Nixie-Controller-v2-BOM.csv, Nixie-Controller-v2.kicad_pcb]
2021-10-07 Update POS file to csv
    [Nixie-Controller-v2-all-pos.csv]
2021-10-07 Remove extra test points
    [Nixie-Controller-v2.kicad_pcb]
2021-10-07 Update fabrication files
    [Nixie-Controller-v2.kicad_pcb]
2021-10-25 Remove uC external crystal
    [Nixie-Controller-v2.kicad_pcb, Nixie-Controller-v2.sch]
2021-10-25 Fix Q2~Q61 footprint (schematic only)
    [Nixie-Controller-v2.sch]
2021-10-26 Redesign larger PCB layout
    [Nixie-Controller-v2.kicad_pcb]
2021-10-26 Move uC towards middle of PCB for optimal WiFi positioning
    [Nixie-Controller-v2.kicad_pcb]
2021-10-26 Fix GND testpoint label orientation
    [Nixie-Controller-v2.kicad_pcb]
2021-10-26 Use generic GPIO pin as SPI nCS
2021-10-26 Use SPI for shift register control
2021-10-26 Connect shift register to SPI ports
    [Nixie-Controller-v2.kicad_pcb, Nixie-Controller-v2.sch]
2021-10-29 Switch HV output cap to 10uF
    [Nixie-Controller-v2.kicad_pcb, Nixie-Controller-v2.sch]
2021-10-29 Add ESP WiFi module
    [Nixie-Controller-v2.kicad_pcb, Nixie-Controller-v2.sch]
2021-10-29 Add ESP UART interface to uC config
2021-10-29 Add WiFi section label to schematic
    [Nixie-Controller-v2.sch]
2021-10-29 Add author and HV info to silkscreen
    [Nixie-Controller-v2.kicad_pcb]
2021-10-29 Fix unconnected bypass cap
    [Nixie-Controller-v2.kicad_pcb]
2021-10-29 Add revision info to silkscreen
    [Nixie-Controller-v2.kicad_pcb]
2021-10-29 Generate fabrication files for v2.0-pre2
    [Nixie-Controller-v2-BOM.csv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]
2021-11-09 Switch to solid connection from barrel jack to power plane
    [Nixie-Controller-v2.kicad_pcb]
2021-11-12 Increase silkscreen text size
    [Nixie-Controller-v2.kicad_pcb]
2021-11-12 Shift HV kelvin line to prevent shorts
    [Nixie-Controller-v2.kicad_pcb]
2021-11-12 Remove status LED
    [Nixie-Controller-v2.kicad_pcb, Nixie-Controller-v2.sch]
2021-11-12 Add reset jumper
    [Nixie-Controller-v2.kicad_pcb, Nixie-Controller-v2.sch]
2021-11-13 Switch to ESP32-WROOM-32E wifi module
    [Nixie-Controller-v2.kicad_pcb, Nixie-Controller-v2.sch]
2021-11-13 Update testpoints & decrease size
    [Nixie-Controller-v2.kicad_pcb, Nixie-Controller-v2.sch]
2021-11-16 Use correct UART ports for ESP32-WROOM-32
    [Nixie-Controller-v2.kicad_pcb, Nixie-Controller-v2.sch]
2021-11-16 Change silkscreen text for v2.0-pre3
    [Nixie-Controller-v2.kicad_pcb]
2021-11-16 Generate fabrication files for v2.0-pre3
    [Nixie-Controller-v2-BOM.csv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]
2021-11-16 Move firmware files to separate repo
    [Nixie-Controller-v2.kicad_pcb, Nixie-Controller-v2.sch]
2022-01-07 Migrate to KiCAD 6
    [Nixie-Controller-v2.kicad_pcb, Nixie-Controller-v2.kicad_sch, Nixie-Controller-v2.sch]
